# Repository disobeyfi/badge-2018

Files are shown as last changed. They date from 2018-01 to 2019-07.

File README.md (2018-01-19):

# Sources for Disobey 2018 badge

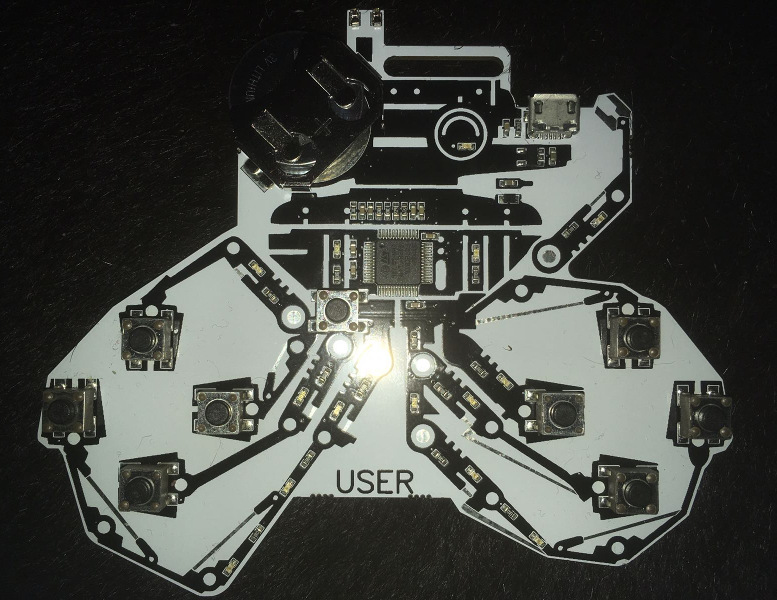
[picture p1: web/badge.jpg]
Image of USER badge


Disobey Badge is an electronic device that was given for all Disobey visitors. It is part of the badge challenge.
The badge uses most of it's time on sleeping and playing simple animations using its leds as a 14-pixel display.
It also includes a game in which the user has to collect keys from all 9 different badge types, to obtain access to further puzzles on the "cloud". Badge is designed to resemble Nintendo style gamepad, and behaves as one when it's plugged to a computer using USB.

## Functional Description

Technically the badge is a device build around STM32F0 microcontroller. It ticks at 8MHz normally with an internal RC oscillator.
Each badge type has it's own binary, and each one of them has a different hardcoded key and led brightness correction parameter.
Communication with other badges is handled through a half-duplex uart. Badge normally operates with a coin battery. When USB power line is connected, the USB power is used instead, and the mcu can detect this by checking a GPIO that's connected to the USB power.

#### Keys

During the boot badge hashes it's current key accumulator using SHA-256. It compares first 32 bits of the hash to list of hashes of all valid key combinations.
(if hash is not found, the accumulator is resetted to badge's internal code) If reset was user-initiated, the key combination bitmask is flashed on the leds for a little period. At the same time uart is polled for incoming communication (fondling) and button gpio's are polled for the first press of the konami code.

#### Data Transfer

If button is pressed during boot, badge goes to a code input mode. In this mode user is expected to press next button in the sequence.
If any other button is pressed, the sequence is resetted to the first step. If no key is pressed for some time, badge goes back to the animation mode. When the code sequence is completed, a pilot signal is sent from the uart. After each pilot signal iteration, badge checks for real incoming transfer.

Badges check if an incoming pilot signal is detected on the boot. If this happens, badge goes directly to the code send mode.
Badge sends its key in a packet that roughly follows the format of [sync][key][key2]. The receiving badge (the one that initiated the exchange) has a sequencer that checks if the sync string has been completely received. After that it tries to receive a key two times. If received keys match, the key accumulator is xorred with the received key. After this the badge reboots as to show the new state of the accumulator, but usually the transfer connection still exists and code send is triggered. This is a bug, but since it didn't seem to cause any (electrical or other) damage, an acute wave of laziness killed any attempts to fix it.

#### USB

If USB power is detected during boot sequence, badge goes to the gamepad mode. In this mode the badge acts as a USB HID Gamepad device with two axes and four buttons. The HID descriptor was generated using Frank Zhao's excellent "USB Descriptor and Request Parser" (http://eleccelerator.com/usbdescreqparser/). USB code is based on Gareth McMullin's example.

If user has pressed keys during boot and gotten to the konami code input, USB power is also polled simultaneously. If its detected, badge presents itself as a HID keyboard instead. After initialization the current status of the key accumulator is written and after this buttons emit keypresses instead.

#### Animations

In animation mode, badge uses random generator to select an animation sequence. Most of the animation sequences are written like two-dimensional functions which are evaluated only on the coordinates of the led lights. This resembles a bit how GPU fragment programs work.

Once "pixel color values" or luminances are evaluated, they are passed to the light driver. Light driver first applies per-board brightness correction, global brightness control (for fade-in/-outs) and gamma correction for the values. Since multiple leds might be connected to some timers and some timers don't control any leds, only the appropriate timer clocks are enabled as to conserve power.

Animations play for a random time. After this RTC wakeup interrupt is set up, and MCU goes back to the lowest STANDBY mode. Waking from this mode is pretty much same as a system reset, and that's why reset is used as a natural part of the device's usage cycle in a pure data-ish way.

## Building

1. get source
2. make symlink called "libopencm3" that points to LibOpenCM3 base directory (http://libopencm3.org/)
3. install arm-none-eabi-gcc (One from Ubuntu repo f.ex. works, no CodeSourcery needed)
4. "make"
5. If you have Texane's STLINK tools, you can program badges directly by running "make badge-type-ledcolor.stlink-flash"

## Bonus
### Taranis Receiver

This repo also features source for a SBUS-to-USB adapter, which can be used (with an appropriate RX hardware such as XM+ or D4R-II) to remotely connect Taranis or Futaba (untested) RC controller to a computer as a game controller.

The resulting adapter controller works with atleast LiftOff quadrotor game/simulator. Adapter currently provides all 16 SBUS channels to the computer as axes.

You can program this to your badge by running "make taranis.stlink-flash"

#### Hardware modification
To prepare your badge for SBUS adapter usage, you'll just need to solder some wires from your RX to the badge.
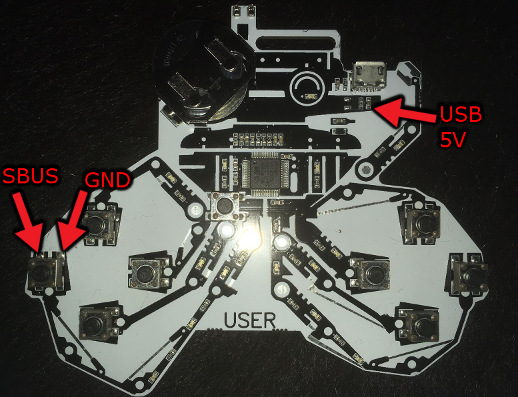
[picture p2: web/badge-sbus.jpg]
Wiring diagram


## Credits

### Product Team
* Heikki Juva - HW design, manufacturing and managering
* Markus Pyykkö - Embedded software, assembly line software
* Valtteri Raila - Idea for the gamepad, all cloud service parts of the puzzle, forcing of people to meet each other

### Thanks
* Authors of excellent (and free) LibOpenCM3 (http://libopencm3.org/)
* NotMyNick - The Father of Disobey
* Guttula - Help in early brainstorming sessions
* Hacklab Helsinki - Providing a electronics lab during development

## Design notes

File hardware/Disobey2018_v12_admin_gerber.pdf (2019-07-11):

TopPaste.gbr Scale=1.00 Sun Jan 21 12:24:35 2018

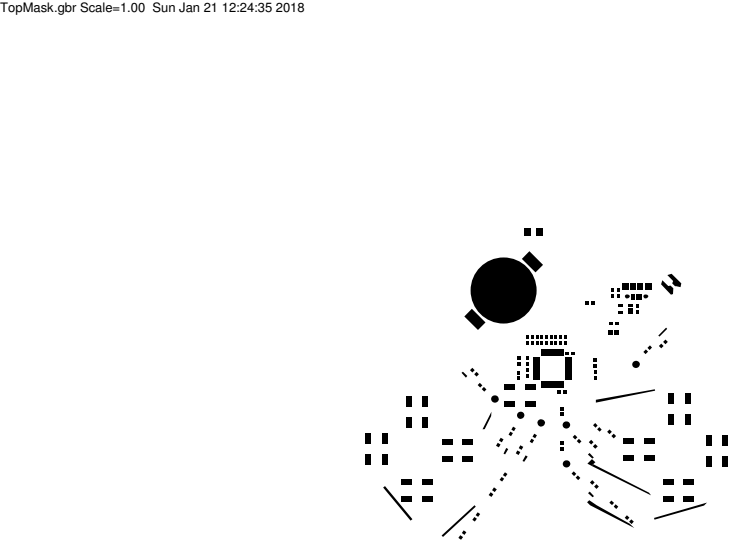
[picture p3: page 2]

TopMask.gbr Scale=1.00 Sun Jan 21 12:24:35 2018

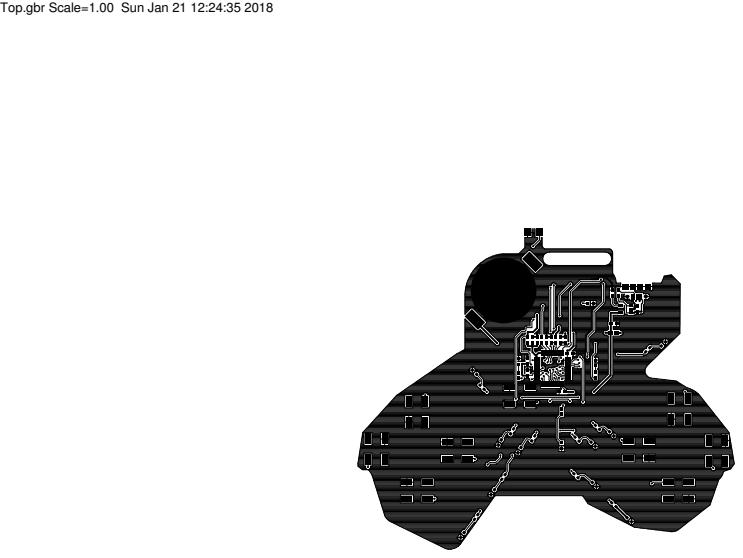
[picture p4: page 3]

Top.gbr Scale=1.00 Sun Jan 21 12:24:35 2018

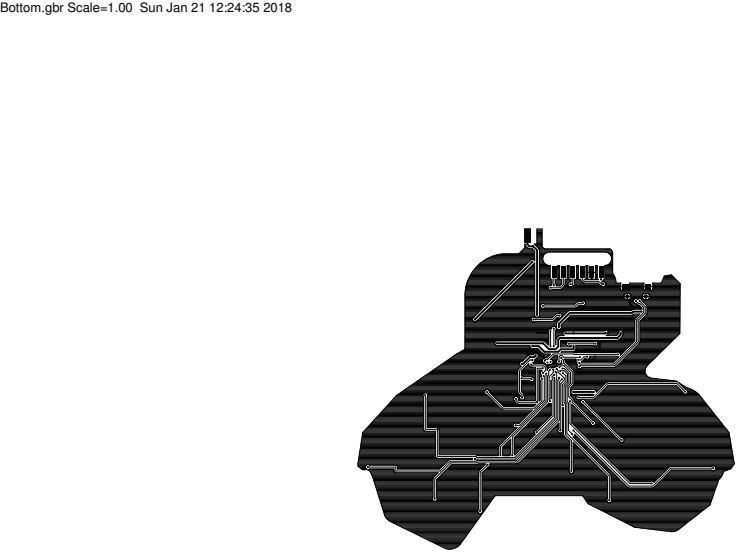
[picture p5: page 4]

Bottom.gbr Scale=1.00 Sun Jan 21 12:24:35 2018

BottomMask.gbr Scale=1.00 Sun Jan 21 12:24:35 2018

BottomPaste.gbr Scale=1.00 Sun Jan 21 12:24:35 201 8

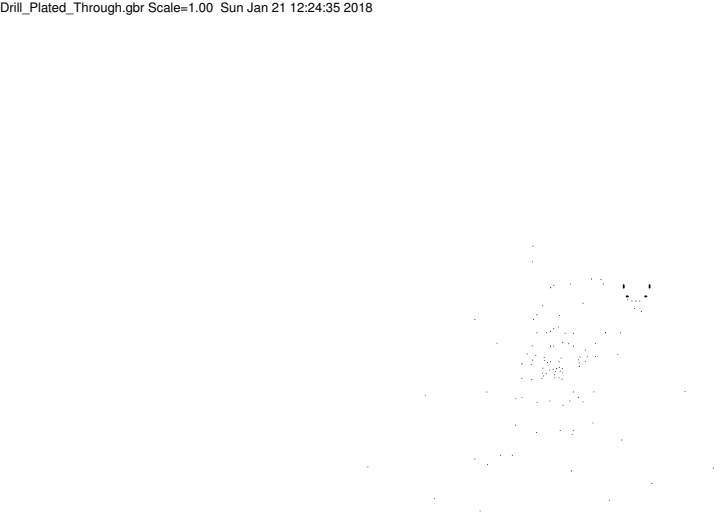
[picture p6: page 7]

Drill_Plated_Through.gbr Scale=1.00 Sun Jan 21 12:24:35 2018

BoardOutline.gbr Scale=1.00 Sun Jan 21 12:24:35 2018

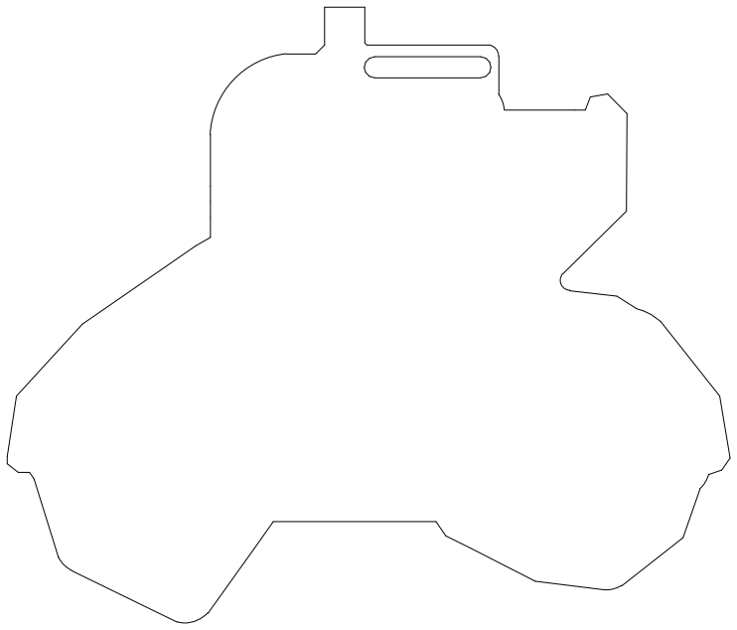
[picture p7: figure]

Board.gbr Scale=1.00 Sun Jan 21 12:24:35 2018

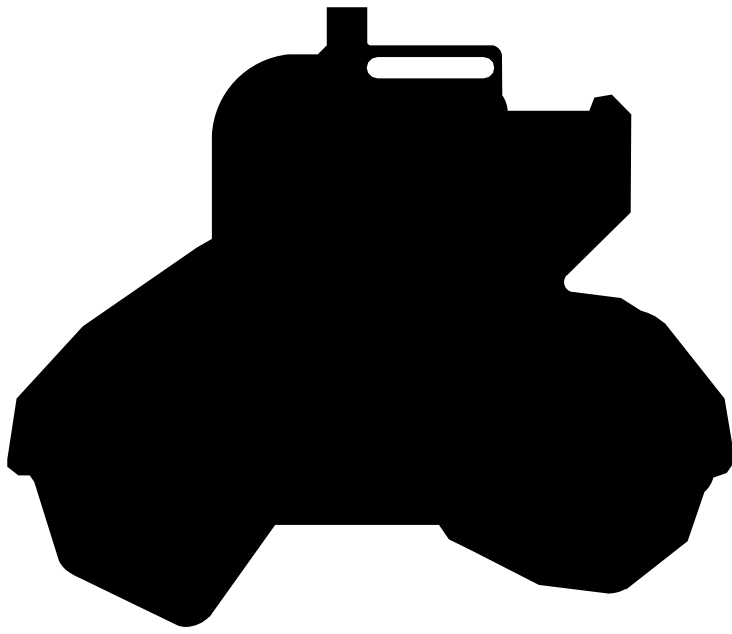
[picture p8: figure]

BottomAssy.gbr Scale=1.00 Sun Jan 21 12:24:35 2018

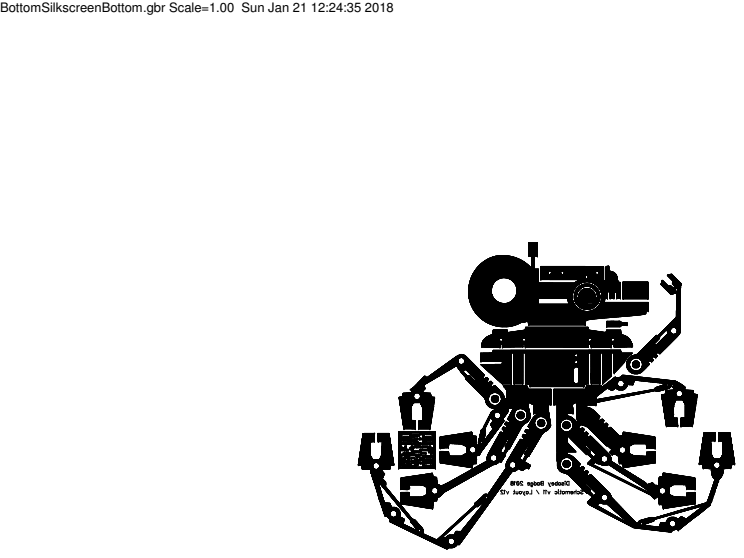
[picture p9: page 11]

BottomSilkscreenBottom.gbr Scale=1.00 Sun Jan 21 12:24:35 2018

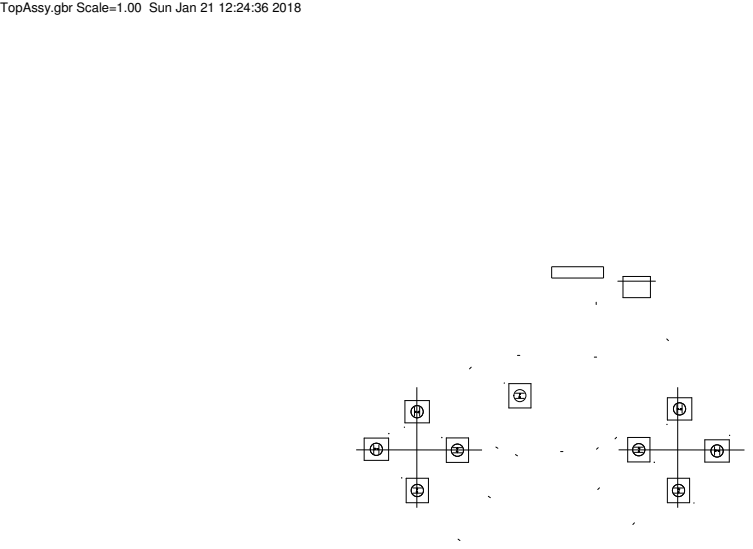
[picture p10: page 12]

TopAssy.gbr Scale=1.00 Sun Jan 21 12:24:36 2018

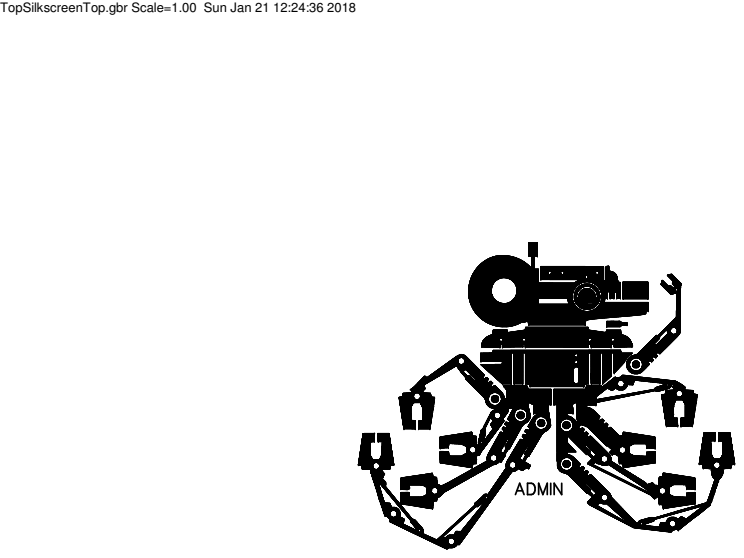
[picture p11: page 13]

TopSilkscreenTop.gbr Scale=1.00 Sun Jan 21 12:24:36 2018

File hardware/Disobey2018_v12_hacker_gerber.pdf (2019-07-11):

TopPaste.gbr Scale=1.00 Sun Jan 21 12:29:02 2018

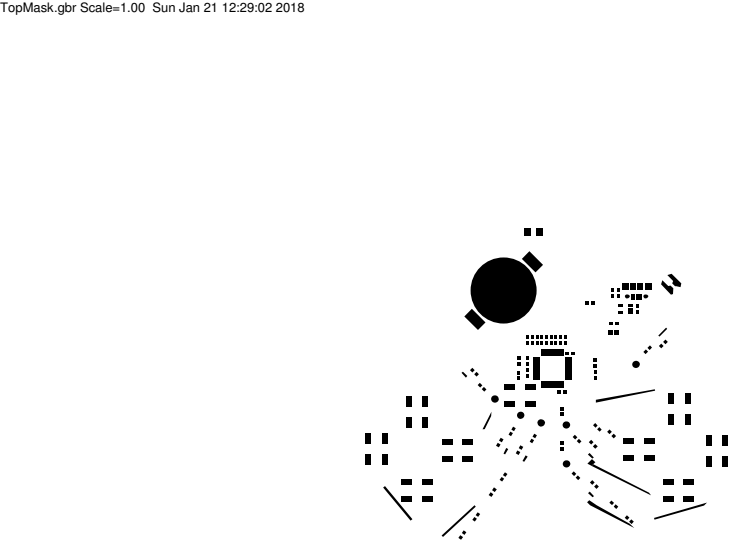
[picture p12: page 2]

TopMask.gbr Scale=1.00 Sun Jan 21 12:29:02 2018

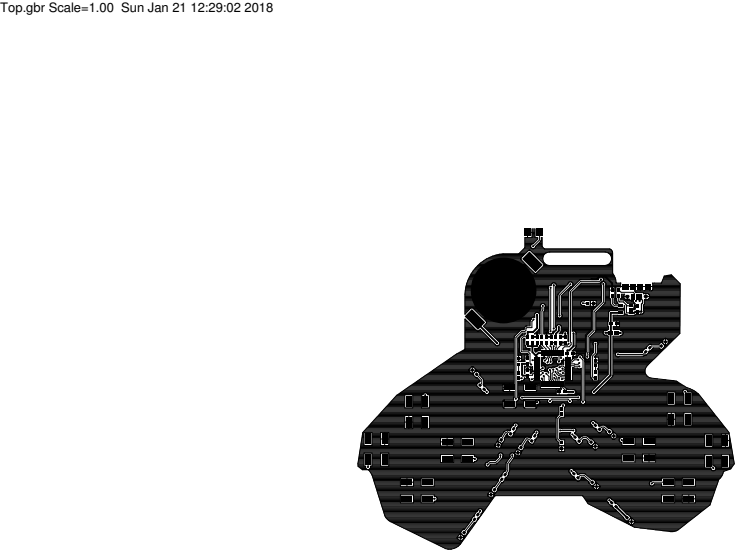
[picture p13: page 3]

Top.gbr Scale=1.00 Sun Jan 21 12:29:02 2018

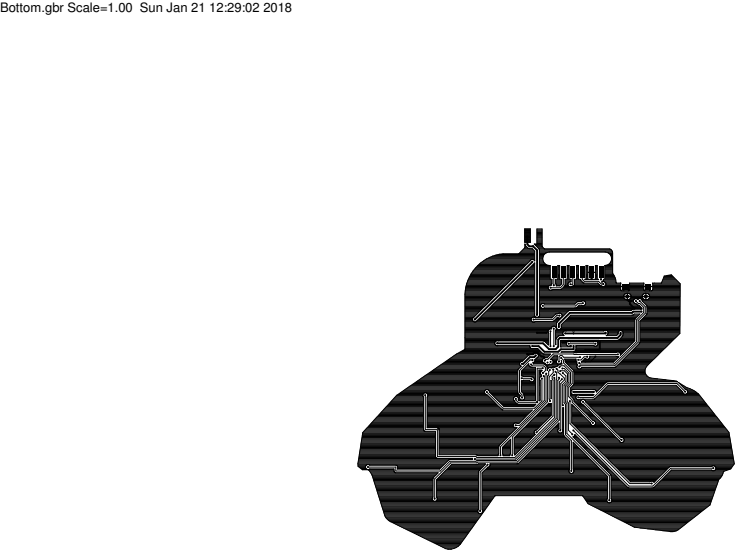
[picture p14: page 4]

Bottom.gbr Scale=1.00 Sun Jan 21 12:29:02 2018

BottomMask.gbr Scale=1.00 Sun Jan 21 12:29:02 2018

BottomPaste.gbr Scale=1.00 Sun Jan 21 12:29:02 201 8

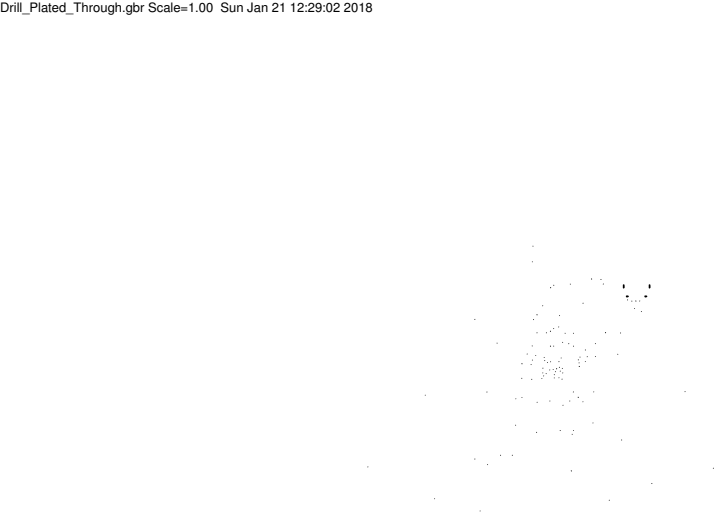
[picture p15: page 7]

Drill_Plated_Through.gbr Scale=1.00 Sun Jan 21 12:29:02 2018

BoardOutline.gbr Scale=1.00 Sun Jan 21 12:29:02 2018


Board.gbr Scale=1.00 Sun Jan 21 12:29:02 2018


BottomAssy.gbr Scale=1.00 Sun Jan 21 12:29:02 2018

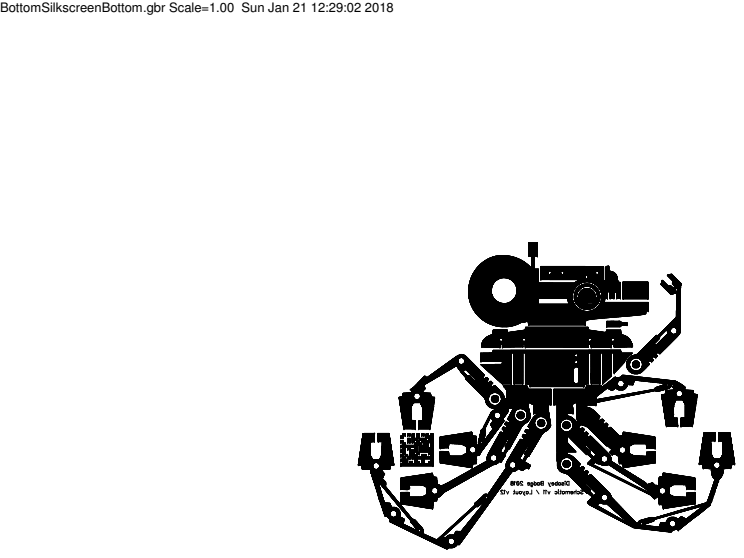
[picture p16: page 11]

BottomSilkscreenBottom.gbr Scale=1.00 Sun Jan 21 12:29:02 2018

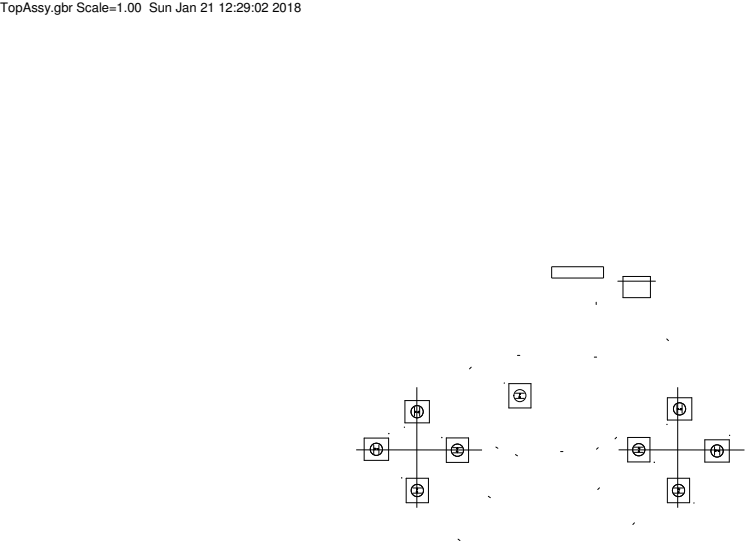
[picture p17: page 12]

TopAssy.gbr Scale=1.00 Sun Jan 21 12:29:02 2018

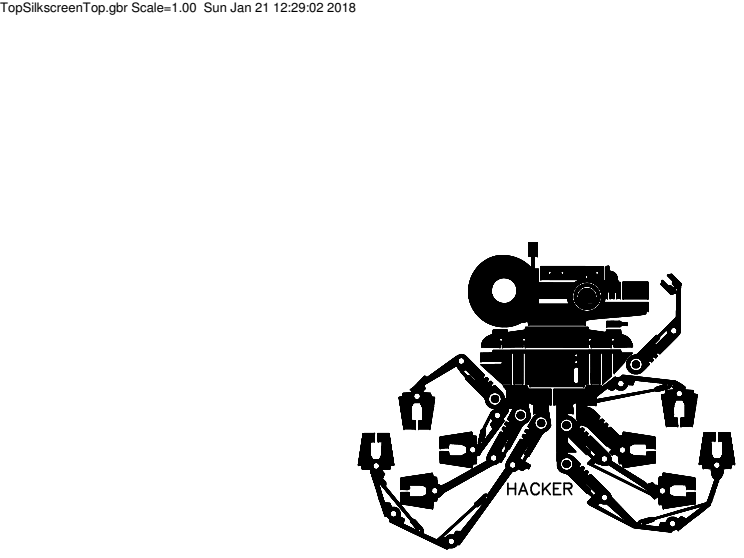
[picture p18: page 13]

TopSilkscreenTop.gbr Scale=1.00 Sun Jan 21 12:29:02 2018

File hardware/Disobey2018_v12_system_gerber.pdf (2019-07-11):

TopPaste.gbr Scale=1.00 Sun Jan 21 12:29:51 2018

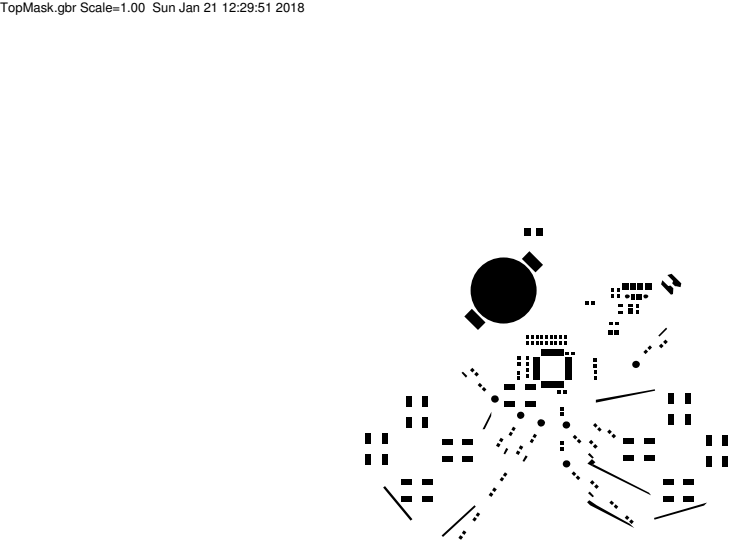
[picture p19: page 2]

TopMask.gbr Scale=1.00 Sun Jan 21 12:29:51 2018

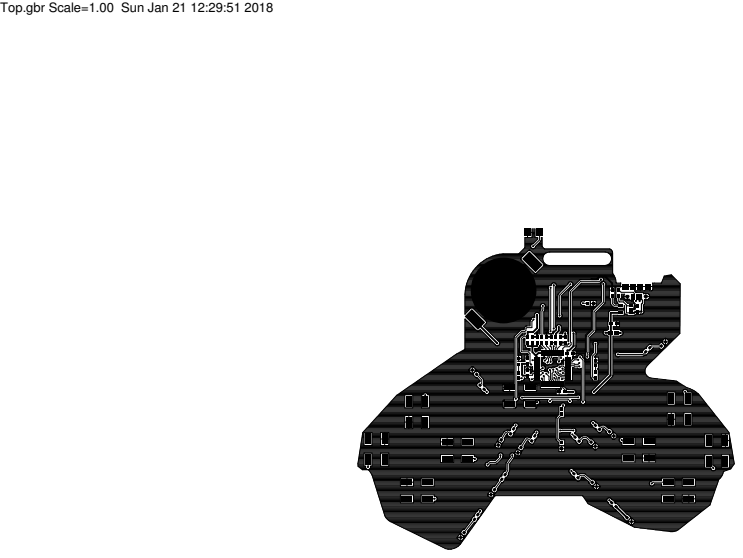
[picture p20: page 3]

Top.gbr Scale=1.00 Sun Jan 21 12:29:51 2018

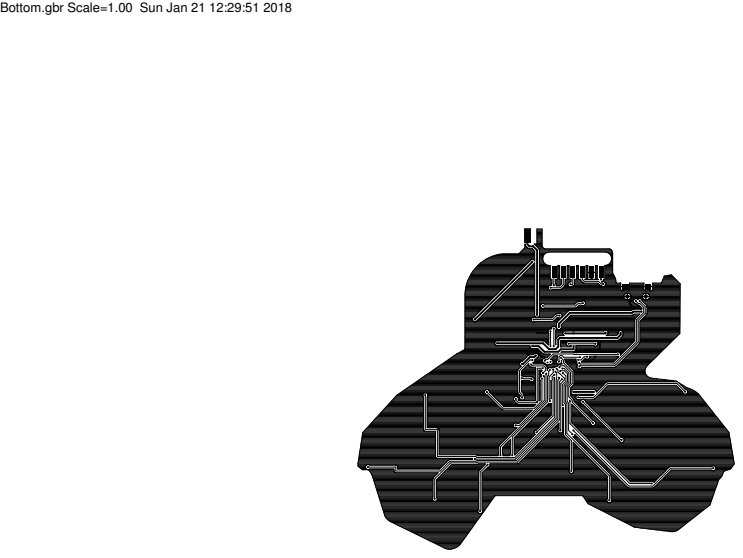
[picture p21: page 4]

Bottom.gbr Scale=1.00 Sun Jan 21 12:29:51 2018

BottomMask.gbr Scale=1.00 Sun Jan 21 12:29:51 2018

BottomPaste.gbr Scale=1.00 Sun Jan 21 12:29:51 201 8

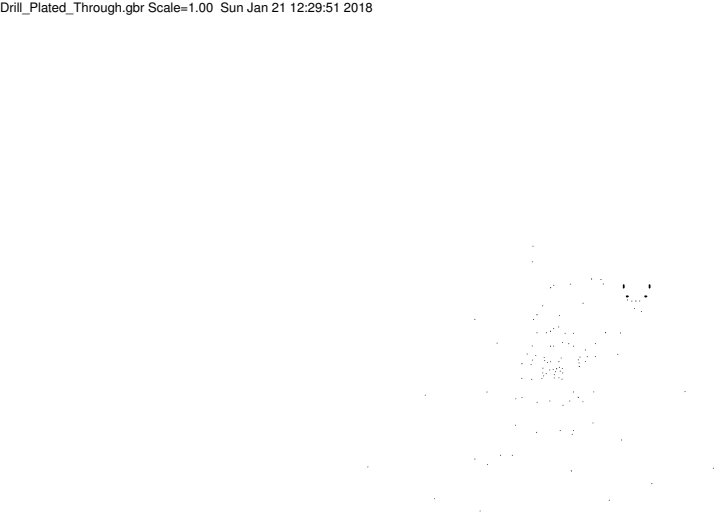
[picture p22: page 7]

Drill_Plated_Through.gbr Scale=1.00 Sun Jan 21 12:29:51 2018

BoardOutline.gbr Scale=1.00 Sun Jan 21 12:29:51 2018


Board.gbr Scale=1.00 Sun Jan 21 12:29:51 2018


BottomAssy.gbr Scale=1.00 Sun Jan 21 12:29:51 2018

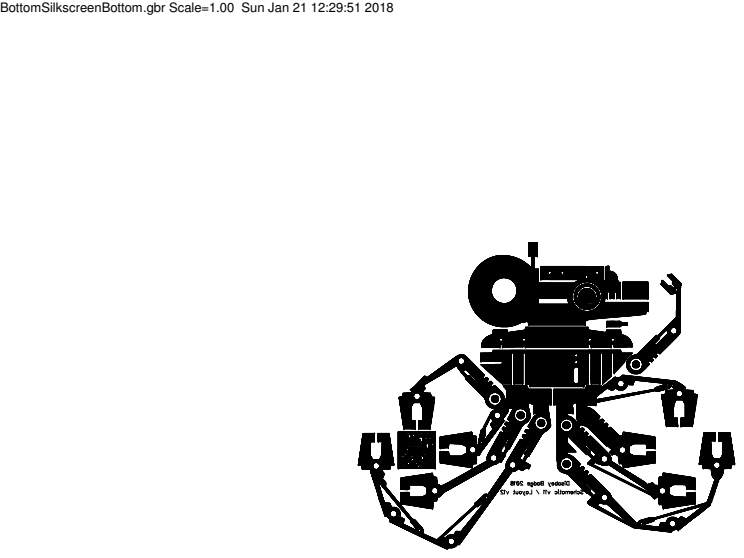
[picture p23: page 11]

BottomSilkscreenBottom.gbr Scale=1.00 Sun Jan 21 12:29:51 2018

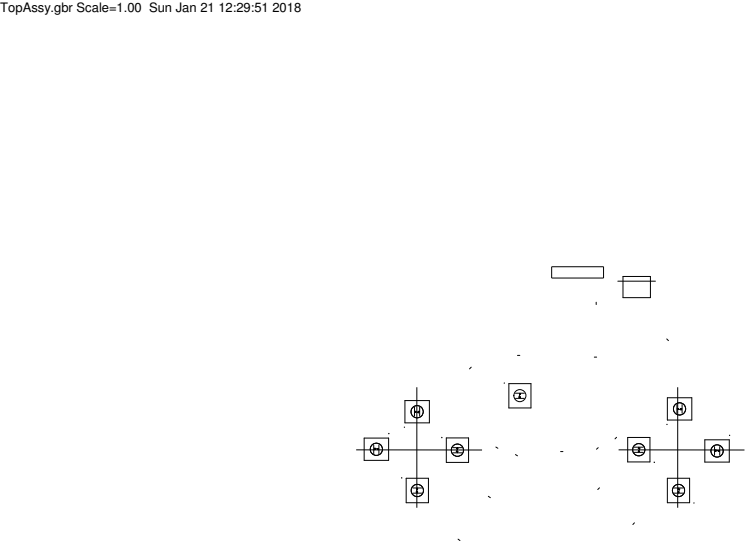
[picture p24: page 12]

TopAssy.gbr Scale=1.00 Sun Jan 21 12:29:51 2018

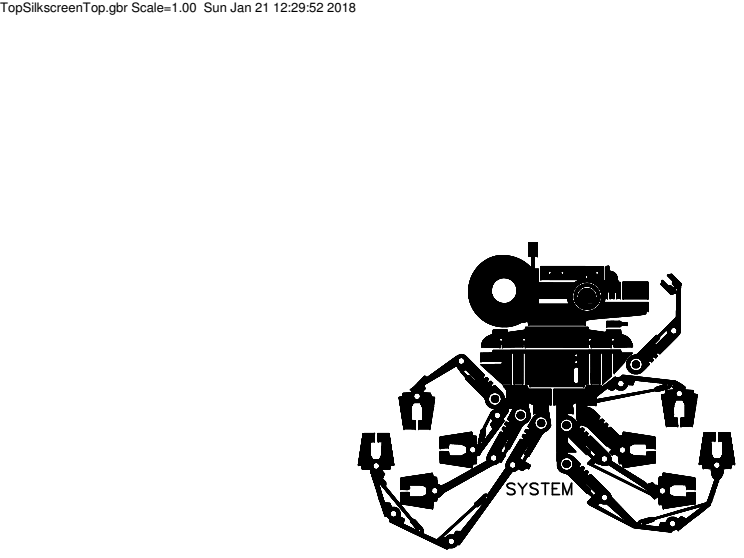
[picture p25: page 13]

TopSilkscreenTop.gbr Scale=1.00 Sun Jan 21 12:29:52 2018

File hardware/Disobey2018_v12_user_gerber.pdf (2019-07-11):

TopPaste.gbr Scale=1.00 Sun Jan 21 12:30:34 2018

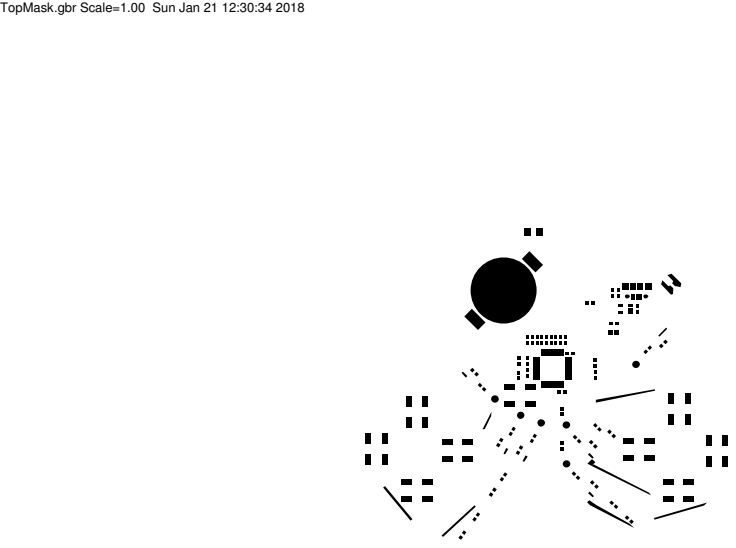
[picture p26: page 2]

TopMask.gbr Scale=1.00 Sun Jan 21 12:30:34 2018


Top.gbr Scale=1.00 Sun Jan 21 12:30:34 2018


Bottom.gbr Scale=1.00 Sun Jan 21 12:30:34 2018

BottomMask.gbr Scale=1.00 Sun Jan 21 12:30:34 2018

BottomPaste.gbr Scale=1.00 Sun Jan 21 12:30:34 201 8


Drill_Plated_Through.gbr Scale=1.00 Sun Jan 21 12:30:34 2018

BoardOutline.gbr Scale=1.00 Sun Jan 21 12:30:34 2018


Board.gbr Scale=1.00 Sun Jan 21 12:30:34 2018


BottomAssy.gbr Scale=1.00 Sun Jan 21 12:30:34 2018


BottomSilkscreenBottom.gbr Scale=1.00 Sun Jan 21 12:30:34 2018


TopAssy.gbr Scale=1.00 Sun Jan 21 12:30:34 2018


TopSilkscreenTop.gbr Scale=1.00 Sun Jan 21 12:30:34 2018

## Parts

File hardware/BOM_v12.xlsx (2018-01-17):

RefDes | Value | Name | Part | Quantity | Digikey REF | Pattern | Manufacturer | Remark
B1 |  | BR1225-1VC | Part 1 | 1 | 36-3034-ND | BK-912 | Panasonic
B101 | RESET | TACTILE SPST-NO J-LEAD | Part 1 | 1 | EG4374TR-ND | TL33 | E-Switch
B102 | UP | TACTILE SPST-NO J-LEAD | Part 1 | 1 | EG4374TR-ND | TL33 | E-Switch
B103 | START | TACTILE SPST-NO J-LEAD | Part 1 | 1 | EG4374TR-ND | TL33 | E-Switch
B104 | A | TACTILE SPST-NO J-LEAD | Part 1 | 1 | EG4374TR-ND | TL33 | E-Switch
B105 | LEFT | TACTILE SPST-NO J-LEAD | Part 1 | 1 | EG4374TR-ND | TL33 | E-Switch
B106 | RIGHT | TACTILE SPST-NO J-LEAD | Part 1 | 1 | EG4374TR-ND | TL33 | E-Switch
B107 | SELECT | TACTILE SPST-NO J-LEAD | Part 1 | 1 | EG4374TR-ND | TL33 | E-Switch
B108 | B | TACTILE SPST-NO J-LEAD | Part 1 | 1 | EG4374TR-ND | TL33 | E-Switch
B109 | DOWN | TACTILE SPST-NO J-LEAD | Part 1 | 1 | EG4374TR-ND | TL33 | E-Switch
C1 | 4u7 | CAP_0603 | Part 1 | 1 |  | CAP 0603 Sulaon
C2 | 100n | CAP_0603 | Part 1 | 1 |  | CAP 0603 Sulaon
C3 | 100n | CAP_0603 | Part 1 | 1 |  | CAP 0603 Sulaon
C4 | 100n | CAP_0603 | Part 1 | 1 |  | CAP 0603 Sulaon
C5 | 4u7 | CAP_0603 | Part 1 | 1 |  | CAP 0603 Sulaon
C6 | 100n | CAP_0603 | Part 1 | 1 |  | CAP 0603 Sulaon
C7 | 1u | CAP_0603 | Part 1 | 1 |  | CAP 0603 Sulaon
C8 | 10n | CAP_0603 | Part 1 | 1 |  | CAP 0603 Sulaon
C11 | 1u | CAP_0603 | Part 1 | 1 |  | CAP 0603 Sulaon
C12 | 1u | CAP_0603 | Part 1 | 1 |  | CAP 0603 Sulaon
C13 | 10n | CAP_0603 | Part 1 | 1 |  | CAP 0603 Sulaon
D2 |  | DIODE_0603 | Part 1 | 1 | CUS08F30H3FCT-ND | DIO_0603
J1 | ADD-ON | 644456-6 | Part 1 | 1 |  | HDR-1x6SH/2.54/15x13 | TE Connectivity | Not populated
J2 |  | 2.2mm spring clip | Part 1 | 1 | WM12438TR-ND | 2,2mm spring clip | Molex
J3 |  | Micro USB (F) | Part 1 | 1 | 609-4618-1-ND | Amphenol HPL_511 | Amphenol
J4 |  | 2.2mm spring clip | Part 1 | 1 | WM12438TR-ND | 2,2mm spring clip | Molex
R1 | 10k | RES_0603 | Part 1 | 1 |  | RES 0603 Sulaon
R5 | 510k | RES_0603 | Part 1 | 1 |  | RES 0603 Sulaon
R6 | 10k | RES_0603 | Part 1 | 1 |  | RES 0603 Sulaon
R7 | 270k | RES_0603 | Part 1 | 1 |  | RES 0603 Sulaon
R12 | 10k | RES_0603 | Part 1 | 1 |  | RES 0603 Sulaon
R101 | 330 | RES_0603 | Part 1 | 1 |  | RES 0603 Sulaon
R102 | 330 | RES_0603 | Part 1 | 1 |  | RES 0603 Sulaon
R103 | 330 | RES_0603 | Part 1 | 1 |  | RES 0603 Sulaon
R104 | 330 | RES_0603 | Part 1 | 1 |  | RES 0603 Sulaon
R105 | 330 | RES_0603 | Part 1 | 1 |  | RES 0603 Sulaon
R106 | 330 | RES_0603 | Part 1 | 1 |  | RES 0603 Sulaon
R107 | 330 | RES_0603 | Part 1 | 1 |  | RES 0603 Sulaon
R108 | 330 | RES_0603 | Part 1 | 1 |  | RES 0603 Sulaon
R109 | 330 | RES_0603 | Part 1 | 1 |  | RES 0603 Sulaon
R110 | 330 | RES_0603 | Part 1 | 1 |  | RES 0603 Sulaon
R111 | 330 | RES_0603 | Part 1 | 1 |  | RES 0603 Sulaon
R112 | 330 | RES_0603 | Part 1 | 1 |  | RES 0603 Sulaon
R113 | 330 | RES_0603 | Part 1 | 1 |  | RES 0603 Sulaon
R114 | 330 | RES_0603 | Part 1 | 1 |  | RES 0603 Sulaon
U1 |  | STM32F072C8T6 | Part 1 | 1 | 497-17358-ND | QFP-48/9x9x0.5
U2 |  | LP3985 | Part 1 | 1 | LP3985IM5-3.3/NOPBCT-ND | SOT23-5 | Texas Instruments
U101 |  | LED 0603 Sulaon | Part 1 | 1 |  | LED 0603 Sulaon
U102 |  | LED 0603 Sulaon | Part 1 | 1 |  | LED 0603 Sulaon
U103 |  | LED 0603 Sulaon | Part 1 | 1 |  | LED 0603 Sulaon
U104 |  | LED 0603 Sulaon | Part 1 | 1 |  | LED 0603 Sulaon
U105 |  | LED 0603 Sulaon | Part 1 | 1 |  | LED 0603 Sulaon
U106 |  | LED 0603 Sulaon | Part 1 | 1 |  | LED 0603 Sulaon
U107 |  | LED 0603 Sulaon | Part 1 | 1 |  | LED 0603 Sulaon
U108 |  | LED 0603 Sulaon | Part 1 | 1 |  | LED 0603 Sulaon
U109 |  | LED 0603 Sulaon | Part 1 | 1 |  | LED 0603 Sulaon
U110 |  | LED 0603 Sulaon | Part 1 | 1 |  | LED 0603 Sulaon
U111 |  | LED 0603 Sulaon | Part 1 | 1 |  | LED 0603 Sulaon
U112 |  | LED 0603 Sulaon | Part 1 | 1 |  | LED 0603 Sulaon
U113 |  | LED 0603 Sulaon | Part 1 | 1 |  | LED 0603 Sulaon
U114 |  | LED 0603 Sulaon | Part 1 | 1 |  | LED 0603 Sulaon

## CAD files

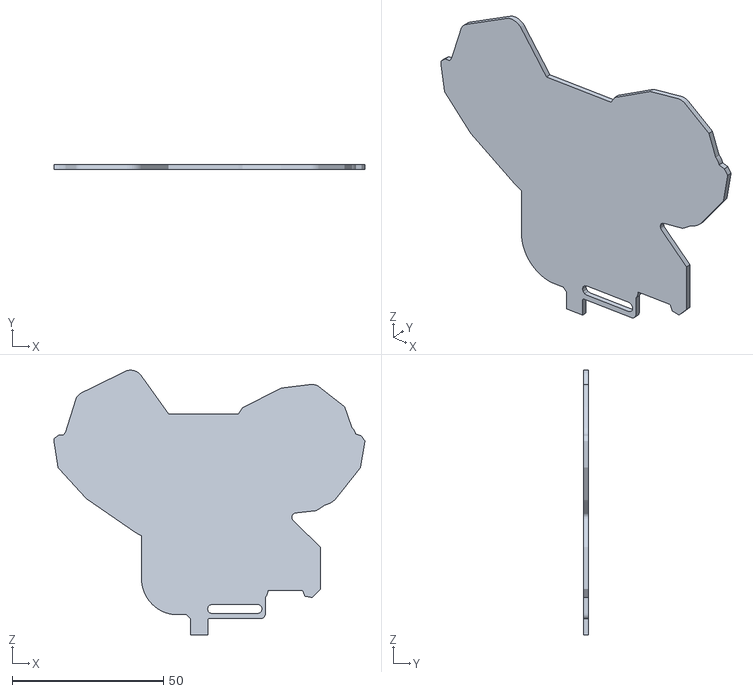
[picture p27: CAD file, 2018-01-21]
hardware/Mechanics/DisobeyBadge2018_v12_final_PCB.stl
102.7 x 1.60 x 87.4

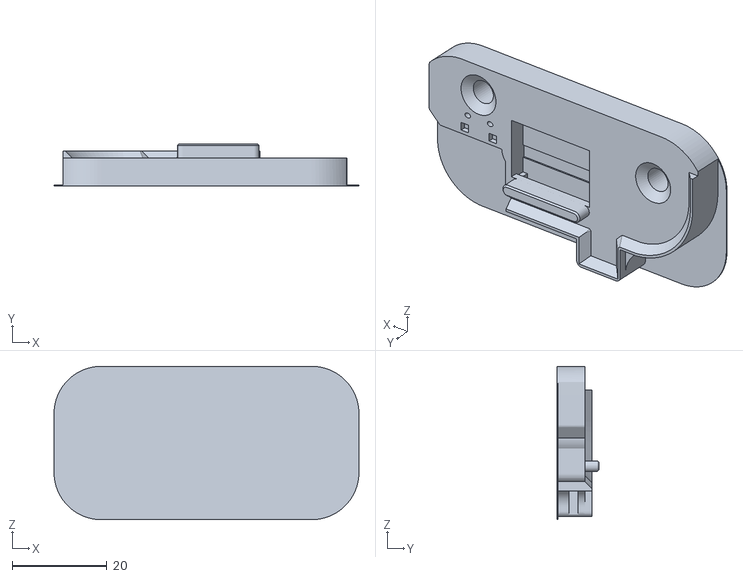
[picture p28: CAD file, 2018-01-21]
hardware/Mechanics/DisobeyBadge2018_v12_final_jig.stl
64.5 x 8.90 x 32.4

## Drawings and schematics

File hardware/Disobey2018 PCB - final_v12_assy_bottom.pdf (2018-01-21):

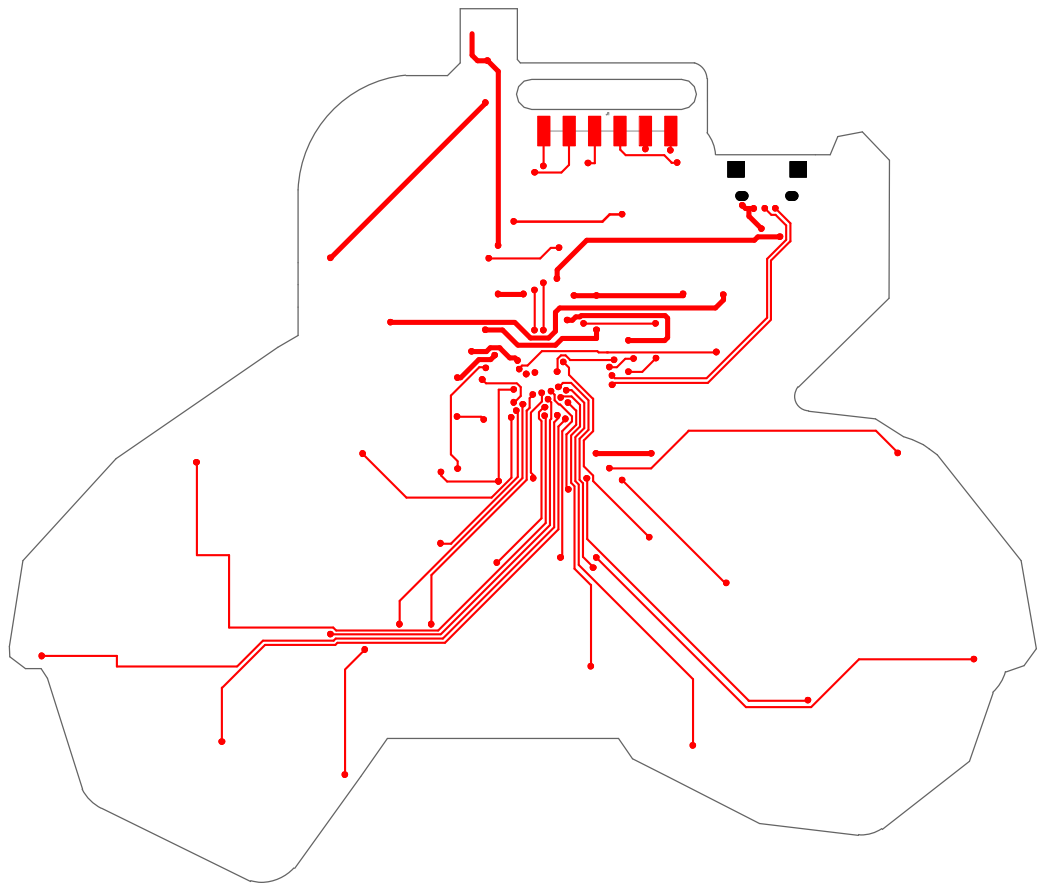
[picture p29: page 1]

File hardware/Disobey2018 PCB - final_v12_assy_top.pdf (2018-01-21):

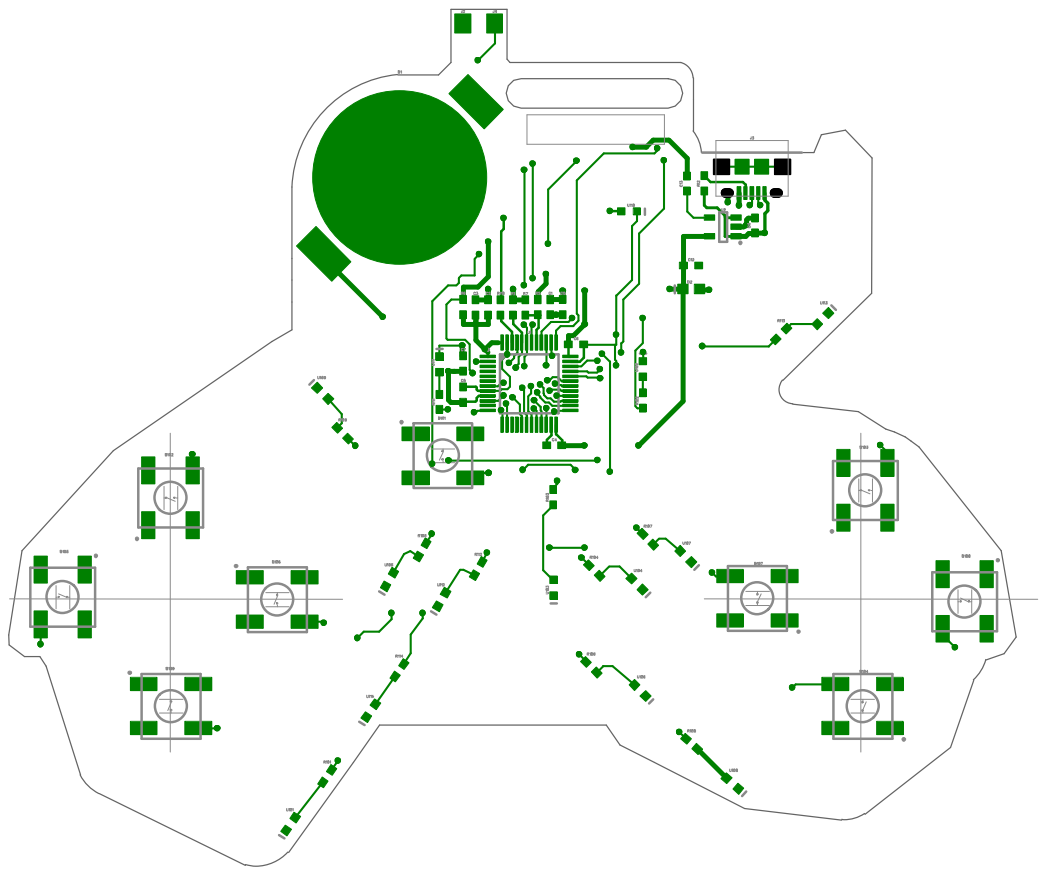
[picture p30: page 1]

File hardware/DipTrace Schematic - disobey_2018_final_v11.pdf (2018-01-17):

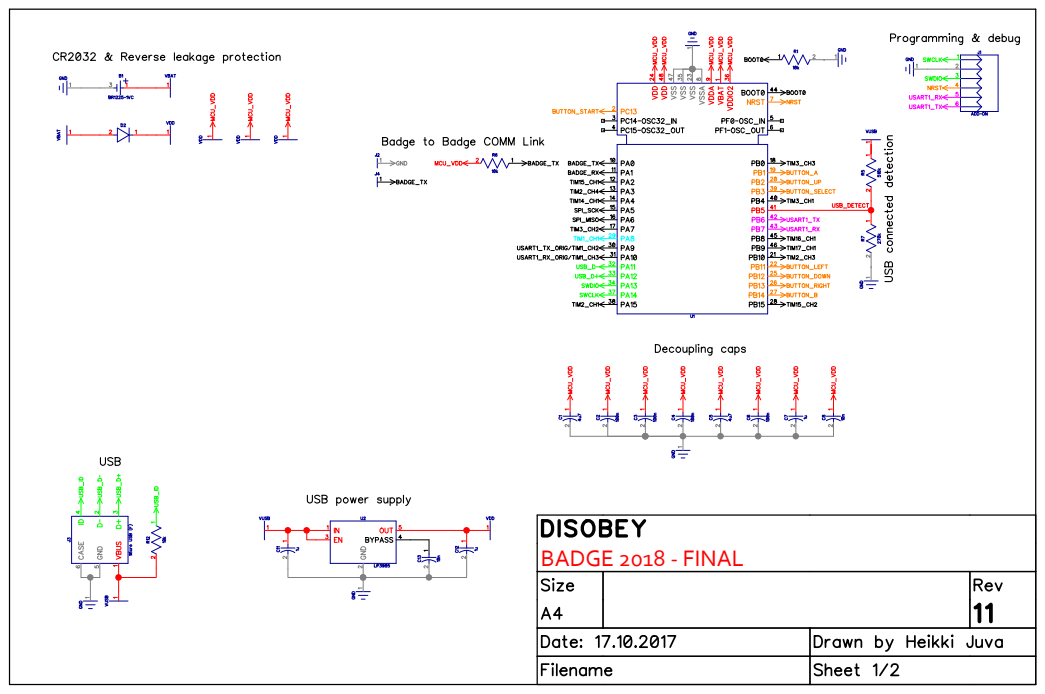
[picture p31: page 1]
BADGE 2018 - FINAL

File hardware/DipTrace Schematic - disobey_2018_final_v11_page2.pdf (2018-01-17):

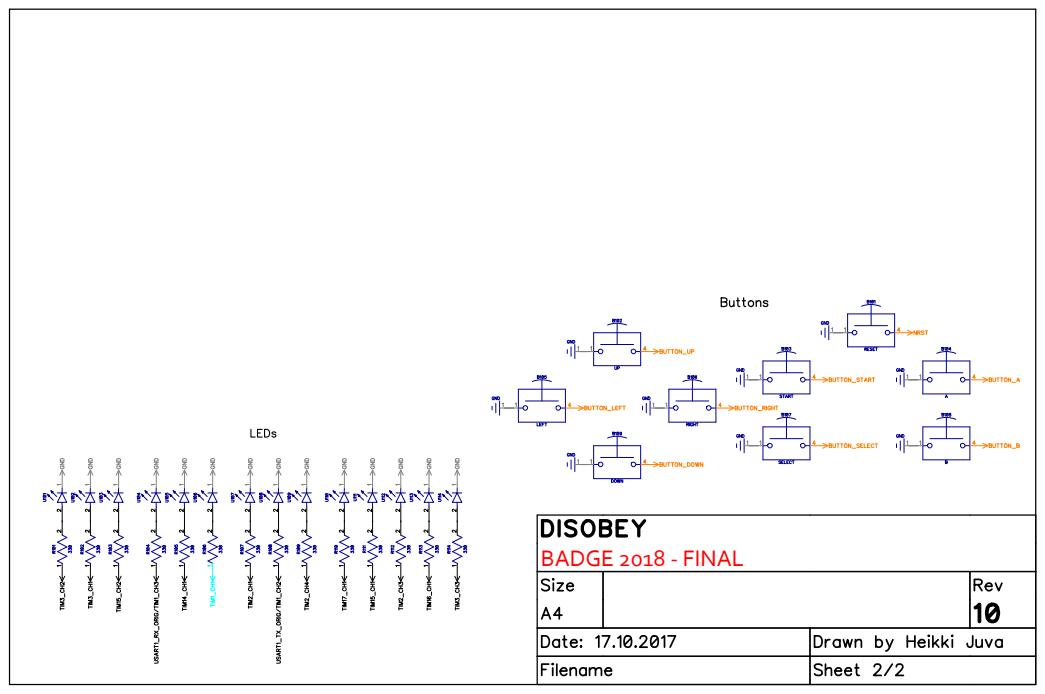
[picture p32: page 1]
BADGE 2018 - FINAL

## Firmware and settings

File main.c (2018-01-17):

/*
 * This file is part of Disobey Badge 2018 firmware.
 *
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
 * You should have received a copy of the GNU General Public License
 * along with Disobey Badge 2018 firmware.  If not, see <http://www.gnu.org/licenses/>.
 */

#include <libopencmsis/core_cm3.h>

#include <libopencm3/cm3/nvic.h>
#include <libopencm3/cm3/scb.h>

#include <libopencm3/stm32/rcc.h>
#include <libopencm3/stm32/gpio.h>
#include <libopencm3/stm32/rtc.h>
#include <libopencm3/stm32/pwr.h>

#include <libopencm3/stm32/exti.h>
#include <libopencm3/stm32/usart.h>

#include <libopencm3/stm32/timer.h>

#include <stdbool.h>

#include <stdio.h>

#include <stdlib.h>
#include <math.h>
#include <string.h>

#include "utils.h" 
#include "debugf.h"
#include "lights.h"
#include "buttons.h"
#include "fondling.h"
#include "animations.h"

#include "keys/badgekey.h"

const bool enable_gp_usb = 1;
const bool enable_kb_usb = 1;

void keyboard(int keybits, const char *keystring);
void gamepad(void);


// key handling integration
extern badgekey_t mykey;
extern uint32_t keycombos[];

badgekey_t key_current;
int key_bits = 0;

void updatekeybits()
{
	uint32_t keyhash = key_gethash(&key_current);

	key_bits = 0;

	for (int i = 0; i < 512; i++)
	{
		if (keyhash == keycombos[i])
		{
			key_bits = i;
		}
	}
}

void loadkey()
{
	uint32_t *key32 = (uint32_t *)key_current.key;

	rtc_unlock();
	key32[0] = RTC_BKPXR(1);
	key32[1] = RTC_BKPXR(2);
	key32[2] = RTC_BKPXR(3);
	key32[3] = RTC_BKPXR(4);
	rtc_lock();

	updatekeybits();

	if (key_bits == 0)
	{
		key_current = mykey;
		updatekeybits();
	}

	debugf("Restored key bits: 0x%X/0x1FF\r\n", key_bits);

}

void savekey()
{
	uint32_t *key32 = (uint32_t *)key_current.key;

	rtc_unlock();
	RTC_BKPXR(1) = key32[0];
	RTC_BKPXR(2) = key32[1];
	RTC_BKPXR(3) = key32[2];
	RTC_BKPXR(4) = key32[3];
	rtc_lock();
}





char* synctext = "HELP ME OBI-WAN, YOU ARE MY ONLY HOPE... ";

void receivecode()
{
	lights_setup();

	debugf("woah code!\r\n");

#if 0
	int flashy = 0xAAAA;
	for (int i = 0; i < 5; i++)
	{
		flashy ^= 0xFFFF;
		lights_set(flashy);
		sleep_cpu(0x500);
	}
#endif

	int synclen = (int)strlen(synctext);
	int syncpos = 0;
	int mode = 0;

	uint8_t keyhex[33];
	keyhex[32] = 0;

	int keyhexidx = 0;
	int keyhexidx2 = 0;

	int payloadcounter = 0;

	debugf("now recving\r\n");

	while(1)
	{
		int wasted = 0;
		while(1)
		{
			bool isdata = fondling_data_avail();

			if (!isdata)
			{
				sleep_cpu(20);
				wasted++;
				if (wasted == 200)
				{
					debugf("woah ok this is enough!\r\n");
					return;
				}
			}
			else
				break;
		}


		uint16_t poo = usart_recv_blocking(USART4);

		if (syncpos < synclen)
		{
			debugf("%c", poo);

			if (poo == synctext[syncpos])
				syncpos++;
			else
			{
				syncpos = 0;
				debugf("\r\n\r\n");
			}

			mode = 0;
			keyhexidx = 0;
			keyhexidx2 = 0;

			payloadcounter = 70; // just some value that's longer than the payload
		}
		else
		{
			debugf("'%c' ", poo);

			if (mode == 0)
			{
				if (poo == 'x')
					mode = 1;
				else if (keyhexidx < 32)
					keyhex[keyhexidx++] = (uint8_t)poo;
				else
					syncpos = 0;
			}
			else if (mode == 1)
			{
				if (poo == '\r')
					mode = 2;
				else if (keyhexidx2 < 32 && keyhex[keyhexidx2++] == poo)
					{}
				else
					syncpos = 0;
			}

			payloadcounter--;
			if (payloadcounter == 0)
				syncpos = 0;

			else if (poo == '\n' && keyhexidx == 32 && keyhexidx2 == 32)
			{
				badgekey_t inputkey;
				key_fromhex(&inputkey, keyhex);

				debugf("key: '%s', key again: '%s', hash %08X\r\n", keyhex, keyhex, key_gethash(&inputkey));

				key_combine(&key_current, &inputkey);
				savekey();
				scb_reset_system();
				// fuck you :DS:D:D:fg,ifd0ih

				syncpos = 0;
			}
		}

		static int ls = 0xAAAA;
		ls ^= 0xFFFF;
		lights_set(ls);
	}
}

void codesend()
{
	fondling_usart_setup();

	lights_setup();

	char packet[256];

	char keyhex[33];
	keyhex[32] = 0;
	key_gethex(&mykey, keyhex);

	int packetlen = sprintf(packet, "%s%sx%s\r\n", synctext, keyhex, keyhex);

	for (int t = 0; t < 5; t++)
	{
		for (int idx = 0; idx < packetlen; idx++)
		{
			usart_send_blocking(USART4, packet[idx]);
			debugf("sending: '%c'\r\n", packet[idx]);

			static int ls = 1 << 9;
			ls ^= 1 << 10 | 1 << 12;
			lights_set(ls);
			sleep_cpu(0x10);
		}
	}


	scb_reset_system();
}

void codesend_trigger()
{
	fondling_usart_setup();

	lights_setup();

	char packet[256];
	int packetlen = sprintf(packet, "Amiga users like when their antennas touch");

	for (int t = 0; t < 20; t++)
	{
		for (int idx = 0; idx < packetlen; idx++)
		{
			usart_send_blocking(USART4, packet[idx]);
			debugf("sending: '%c'\r\n", packet[idx]);

			static int ls = 0;
			ls ^= 1 << 9;
			lights_set(ls);
			sleep_cpu(0x50);
		}

		usart_recv(USART4);

		for (int i = 0; i < 10; i++)
		{
			static int ls = 0;
			ls ^= 1 << 10 | 1 << 12;
			lights_set(ls);
			sleep_cpu(0x30);

			bool dada = fondling_data_avail();
			debugf("fondling input: %i (try %i)\r\n", dada ? 1 : 0, i);

			if (dada)
			{

#if 0
				while(1)
				{
					lights_set(0xFFFF);
					sleep_cpu(0x300);
					lights_set(0x0000);
					sleep_cpu(0x300);

				}
#endif

				receivecode();
				return;
			}

		}
	}

}




int code[] =
{
	BUTTON(4),
//	BUTTON(4),
	BUTTON(5),
//	BUTTON(5),

	BUTTON(6),
	BUTTON(7),
	BUTTON(6),
	BUTTON(7),
	
	BUTTON(1),
	BUTTON(0),
};
int codelen = 8;

bool input_konamicode_testfirst()
{
	return buttons_read();
}

bool input_konamicode()
{
	lights_setup();
	int ledstate = 0;

	int timer = 50;

	int flashy = 0;
	int seqpos = 0;

	while(timer--)
	{
		int buts = buttons_read();
		if (buts)
		{
			timer = 100;
			if (seqpos < codelen && buts == code[seqpos])
			{
				flashy |= 1 << seqpos;
				seqpos++;
				if (seqpos == codelen)
					break;
			}
			else if (seqpos >= 1 && buts == code[seqpos-1])
			{
			
			}
			else
			{
				flashy = 0;
				ledstate = 0;
				seqpos = 0;
			}
		}

		ledstate ^= flashy;

		lights_set(ledstate);

		if (gpio_get(GPIOB, GPIO5) && enable_kb_usb)
		{
			debugf("late usb detected!\n");

			lights_set(0);


			char keyhex[33];
			keyhex[32] = 0;
			key_gethex(&key_current, keyhex);
			keyboard(key_bits, keyhex);

			// no return from here
		}


		sleep_cpu(0x50);
	}

	lights_kill();
	if (seqpos == codelen)
	{
		return 1;
	}


	return 0;
}

int check_fondling(bool manualreset)
{
	int returncode = 0;

	debugf("Checking for incoming key, keypress and late USB power..\r\n");


	fondling_usart_setup();

	for (int i = 0; i < 50; i++)
	{
		bool dada;
		dada = fondling_data_avail();
//		debugf("fondling input: %i (try %i)\r\n", dada ? 1 : 0, i);
		if (dada)
		{
			//receivecode();
			debugf("incoming uart data detected!\n");

			codesend();
			// no return
		}

		//for (int x = 0; x < 9; x++)
		int curbit = i % 9;
		{
			if (manualreset)
			{
				//int bitmask = (1 << (curbit + 1)) - 1;
				int bitmask = curbit < 4 ? 0 : 0x1FF;

				lights_set((bitmask & key_bits) | (1 << 9));
				sleep_cpu(99);
			}
			else
				sleep_cpu(99);
		}

#if 0
		if (gpio_get(GPIOB, GPIO5) && enable_kb_usb && manualreset)
		{
			debugf("late usb detected!\n");

			lights_set(0);


			char keyhex[33];
			keyhex[32] = 0;
			key_gethex(&key_current, keyhex);
			keyboard(key_bits, keyhex);

			// no return from here
		}
#endif

#if 1
		if (gpio_get(GPIOB, GPIO5) && enable_gp_usb && manualreset)
		{
			lights_kill();
			//debugf("waiting for stabilization..\n");
			//sleep_cpu(10000);
			gamepad();
		}
#endif

		if (manualreset && input_konamicode_testfirst())
		{
			debugf("cheat code detected!\n");

			returncode = 1;
			break;
		}

//		sleep_cpu(0x40);
	}

	fondling_usart_kill();
	return returncode;
}


int main(void)
{
	debug_usart_setup();
	init_usbserial();

#if 0
	{
		gamepad();
	}
#endif

	debugf("\r\n\r\n** Starting up disobey badge ** \r\n");

	initrtc();


	// if device uses too much power, it resets and it might be that
	// the random seed doesn't get updated, leading to same animation again
	// --> reset loop

	rtc_unlock();
	uint32_t seed = RTC_BKPXR(0);
	random_setseed(seed);
	rtc_lock();

	debugf("Advancing the RNG: %lu\r\n", random());

	//goto animations;

	rtc_unlock();
	RTC_BKPXR(0) = random_getseed();
	rtc_lock();

	buttons_setup();

	int bootbuts = buttons_read();
	debugf("Button status on boot: %X\r\n", bootbuts);

	uint32_t resetreason = RCC_CSR & (uint32_t)RCC_CSR_RESET_FLAGS;
	RCC_CSR |= RCC_CSR_RMVF;

	debugf("Reset reason: %08X\r\n", resetreason);

	bool manualreset = resetreason & RCC_CSR_PINRSTF;

	if (manualreset)
	{
		lights_setup();
		lights_set(1 << 9);
	}

	loadkey();

	debugf("Checking for USB power\r\n");
	// TODO: move this to some usb.c
	rcc_periph_clock_enable(RCC_GPIOB);
	gpio_mode_setup(GPIOB, GPIO_MODE_INPUT, GPIO_PUPD_NONE, GPIO5);
	if (gpio_get(GPIOB, GPIO5) && enable_gp_usb)
	{
		lights_kill();
		//debugf("waiting for stabilization..\n");
		//sleep_cpu(10000);
		gamepad();
	}




	int fondling_response = check_fondling(manualreset);


	if (fondling_response)
	{
		int codeid = input_konamicode();

		if (codeid == 1)
		{
			codesend_trigger();
			scb_reset_system();
		}
	}

	buttons_kill();


	animations:
	while (1)
	{
		anim_run();

		int aika = (int)(random() % 8000) + 36000;

		debugf("Storing RNG and going to sleep..\r\n");
		rtc_unlock();
		RTC_BKPXR(0) = random_getseed();
		rtc_lock();

		sleep_standby(aika);
	}

	return 0;
}

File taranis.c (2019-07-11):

/*
 * This file is part of Disobey Badge 2018 firmware.
 *
 * (based on USB example)
 * Copyright (C) 2010 Gareth McMullin <gareth@blacksphere.co.nz>
 *
 * (also uses one Sbus data structure by CleanFlight team!)
 *
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
 * You should have received a copy of the GNU General Public License
 * along with Disobey Badge 2018 firmware.  If not, see <http://www.gnu.org/licenses/>.
 */

#include <stdio.h>
#include <stdlib.h>
#include <libopencm3/cm3/systick.h>
#include <libopencm3/stm32/rcc.h>
#include <libopencm3/stm32/gpio.h>
#include <libopencm3/usb/usbd.h>
#include <libopencm3/usb/hid.h>
#include <libopencm3/stm32/crs.h>
#include <libopencm3/stm32/f0/syscfg.h>
#include <libopencm3/stm32/usart.h>



#include <libopencmsis/core_cm3.h>

#include <libopencm3/cm3/nvic.h>
#include <libopencm3/cm3/scb.h>

#include <libopencm3/stm32/rtc.h>
#include <libopencm3/stm32/pwr.h>

#include <libopencm3/stm32/exti.h>
#include <libopencm3/stm32/usart.h>

#include <libopencm3/stm32/timer.h>

#include <stdbool.h>

#include <math.h>

#include <string.h>

#include "utils.h" 

static usbd_device *usbd_dev;

static const struct usb_device_descriptor dev_descr = {
	.bLength = USB_DT_DEVICE_SIZE,
	.bDescriptorType = USB_DT_DEVICE,
	.bcdUSB = 0x0200,
	.bDeviceClass = 0,
	.bDeviceSubClass = 0,
	.bDeviceProtocol = 0,
	.bMaxPacketSize0 = BULK_EP_MAXPACKET,
	.idVendor = 0xdead,
	.idProduct = 0xcafe,
	.bcdDevice = 0x0001,
	.iManufacturer = 1,
	.iProduct = 2,
	.iSerialNumber = 3,
	.bNumConfigurations = 1,
};

static const uint8_t hid_report_descriptor[] = {
0x05, 0x01,        // Usage Page (Generic Desktop Ctrls)
0x09, 0x05,        // Usage (Game Pad)
0xA1, 0x01,        // Collection (Application)
0xA1, 0x00,        //   Collection (Physical)
0x05, 0x01,        //     Usage Page (Generic Desktop Ctrls)
0x09, 0x30,        //     Usage (X)
0x09, 0x31,        //     Usage (Y)
0x09, 0x32,        //     Usage (Z)
0x09, 0x33,        //     Usage (Rx)
0x09, 0x34,        //     Usage (Ry)
0x09, 0x35,        //     Usage (Rz)
0x09, 0x36,        //     Usage (Slider)
0x09, 0x37,        //     Usage (Dial)
0x09, 0x38,        //     Usage (Wheel)
0x09, 0x39,        //     Usage (Hat switch)
0x09, 0x3A,        //     Usage (Counted Buffer)
0x09, 0x3B,        //     Usage (Byte Count)
0x09, 0x3C,        //     Usage (Motion Wakeup)
0x09, 0x3D,        //     Usage (Start)
0x09, 0x3E,        //     Usage (Select)
0x09, 0x3F,        //     Usage (0x3F)
0x15, 0x00,        //     Logical Minimum (0)
0x26, 0xFF, 0x07,  //     Logical Maximum (2047)
0x75, 0x10,        //     Report Size (16)
0x95, 0x10,        //     Report Count (16)
0x81, 0x02,        //     Input (Data,Var,Abs,No Wrap,Linear,Preferred State,No Null Position)
0xC0,              //   End Collection
0xC0,              // End Collection

// 55 bytes
};

typedef struct {
		uint16_t axes[16];
	} __attribute__((packed)) hidmessage_t;

static const struct {
	struct usb_hid_descriptor hid_descriptor;
	struct {
		uint8_t bReportDescriptorType;
		uint16_t wDescriptorLength;
	} __attribute__((packed)) hid_report;
} __attribute__((packed)) hid_function = {
	.hid_descriptor = {
		.bLength = sizeof(hid_function),
		.bDescriptorType = USB_DT_HID,
		.bcdHID = 0x0100,
		.bCountryCode = 0,
		.bNumDescriptors = 1,
	},
	.hid_report = {
		.bReportDescriptorType = USB_DT_REPORT,
		.wDescriptorLength = sizeof(hid_report_descriptor),
	}
};

const struct usb_endpoint_descriptor hid_endpoint = {
	.bLength = USB_DT_ENDPOINT_SIZE,
	.bDescriptorType = USB_DT_ENDPOINT,
	.bEndpointAddress = 0x81,
	.bmAttributes = USB_ENDPOINT_ATTR_INTERRUPT,
	.wMaxPacketSize = sizeof(hidmessage_t),
	.bInterval = 0x1,
};

const struct usb_interface_descriptor hid_iface = {
	.bLength = USB_DT_INTERFACE_SIZE,
	.bDescriptorType = USB_DT_INTERFACE,
	.bInterfaceNumber = 0,
	.bAlternateSetting = 0,
	.bNumEndpoints = 1,
	.bInterfaceClass = USB_CLASS_HID,
	.bInterfaceSubClass = 0, /* boot */
	.bInterfaceProtocol = 0, /* mouse */

	.iInterface = 0,

	.endpoint = &hid_endpoint,

	.extra = &hid_function,
	.extralen = sizeof(hid_function),
};

const struct usb_interface ifaces[] = {{
	.num_altsetting = 1,
	.altsetting = &hid_iface,
}};

const struct usb_config_descriptor config = {
	.bLength = USB_DT_CONFIGURATION_SIZE,
	.bDescriptorType = USB_DT_CONFIGURATION,
	.wTotalLength = 0,
	.bNumInterfaces = 1,
	.bConfigurationValue = 2,
	.iConfiguration = 1,
	.bmAttributes = 0x80,
	.bMaxPower = 0x32,

	.interface = ifaces,
};

static const char *usb_strings[] = {
	"Disobey Helicopter Gang",
	"SBUS adapter",
	usb_serial,
};

uint8_t hack_flag = 0;

static enum usbd_request_return_codes hid_control_request(usbd_device *dev,
	struct usb_setup_data *req,
	uint8_t **buf,
	uint16_t *len,
	usbd_control_complete_callback *complete)

{
	(void)complete;
	(void)dev;

	if((req->bmRequestType != 0x81) ||
	   (req->bRequest != USB_REQ_GET_DESCRIPTOR) ||
	   (req->wValue != 0x2200))
		return USBD_REQ_NOTSUPP;

	/* Handle the HID report descriptor. */
	*buf = (uint8_t *)hid_report_descriptor;
	*len = sizeof(hid_report_descriptor);

	hack_flag = 1;

	return USBD_REQ_HANDLED;
}

static void hid_set_config(usbd_device *dev, uint16_t wValue)
{
	(void)wValue;
	(void)dev;

	usbd_ep_setup(dev, 0x81, USB_ENDPOINT_ATTR_INTERRUPT, 4, NULL);

	usbd_register_control_callback(
				dev,
				USB_REQ_TYPE_STANDARD | USB_REQ_TYPE_INTERFACE,
				USB_REQ_TYPE_TYPE | USB_REQ_TYPE_RECIPIENT,
				hid_control_request);

}

		int sbusChannelData[16];



void device_work(void)
{
	hidmessage_t msg;

	for (int i = 0; i < 16; i++)
	{
		msg.axes[i] = sbusChannelData[i];
	}

	usbd_ep_write_packet(usbd_dev, 0x81, &msg, sizeof(hidmessage_t));
}


void rescb(void)
{
}

static void sbus_setup(void)
{
	rcc_periph_clock_enable(RCC_USART3);

	rcc_periph_clock_enable(RCC_GPIOB);
	rcc_periph_reset_pulse(RST_USART3);

	gpio_mode_setup(GPIOB, GPIO_MODE_AF, GPIO_PUPD_NONE, GPIO11);
	gpio_set_af(GPIOB, GPIO_AF4, GPIO11);



	usart_set_baudrate(USART3, 100000);
	usart_set_databits(USART3, 9);
	usart_set_parity(USART3, USART_PARITY_EVEN);
	usart_set_stopbits(USART3, USART_STOPBITS_2);
	usart_set_mode(USART3, USART_MODE_RX);
	usart_set_flow_control(USART3, USART_FLOWCONTROL_NONE);
	usart_enable_rx_inversion(USART3);

//	USART3_CR1 &= ~USART_CR1_OVER8;

	nvic_enable_irq(NVIC_USART3_4_IRQ);
	USART_CR1(USART3) |= USART_CR1_RXNEIE;
	//USART_CR2(USART3) |= USART_CR2_MSBFIRST;

	usart_enable(USART3);

	for (int i = 0; i < 16; i++)
	{
		sbusChannelData[i] = 1024; // middle pos
	}

}



#define SBUS_FRAME_SIZE 25
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

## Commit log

2018-01-17 Added files for public release
    [BOM_v11.xlsx]
2018-01-21 Added final hardware layouts and schematics
    [BOM_v12.xlsx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]
2018-01-21 Add gerber PDFs

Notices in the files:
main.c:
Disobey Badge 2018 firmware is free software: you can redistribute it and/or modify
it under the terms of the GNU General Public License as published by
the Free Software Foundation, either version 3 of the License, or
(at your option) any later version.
